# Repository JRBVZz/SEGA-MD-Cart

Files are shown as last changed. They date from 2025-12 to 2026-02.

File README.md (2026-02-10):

#### SEGA MD Cart - картридж для SEGA MegaDrive/Genesis

Простой картридж объемом до 4MB (32Mbit) без сохранений, который можно перезаписывать с помощью программатора [FlashKit MD](https://github.com/JRBVZz/Flashkit-MD).

10.02.2026. Добавил проект PCB с возможностью установки памяти MX29L3211 в корпусе SOP-44.

Для хранения данных используется flash память в корпусе TSOP-48 - S29GL032, MX29LV320, M29W320 и др. Для игр до 2MB можно использовать память меньшего объема.

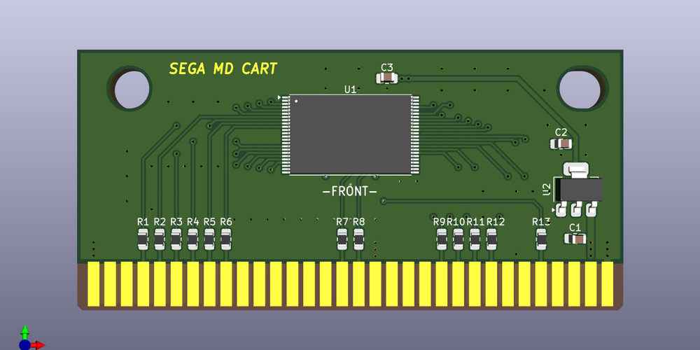
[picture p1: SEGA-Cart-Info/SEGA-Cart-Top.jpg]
3D Top
 

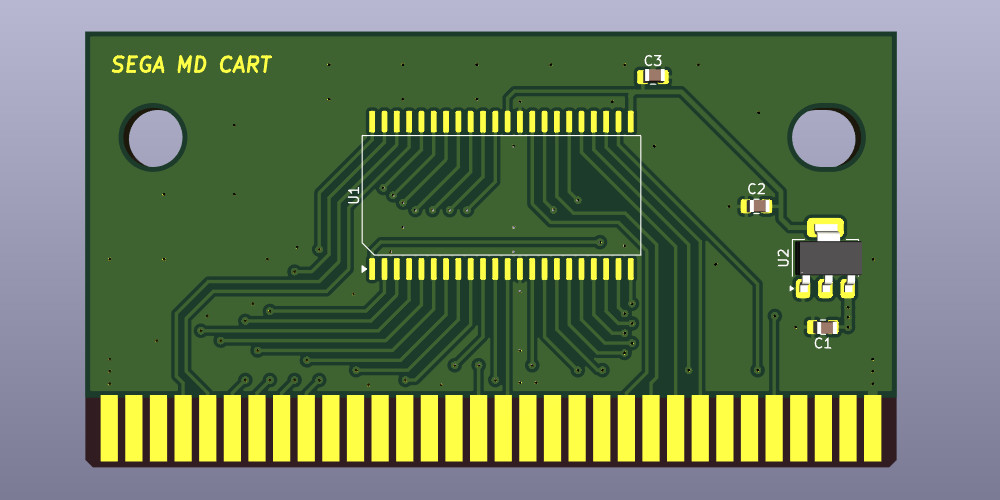
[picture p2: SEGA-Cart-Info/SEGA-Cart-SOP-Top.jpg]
3D Top-SOP


**Параметры для изготовления PCB**  
* 2 слоя
* Толщина PCB: 1.6 мм
* Рекомендуется ENIG покрытие контактов краевого разъема

**Схемы**  
[Schematic PDF](SEGA-Cart-Info/SEGA-Cart-Schematic.pdf)  
[Schematic PDF SOP](SEGA-Cart-Info/SEGA-Cart-SOP-Schematic.pdf)

**Интерактивный BOM**  
[BoM](SEGA-Cart-Info/SEGA-Cart-iBOM.html) (для корректного просмотра нужно скачать raw файл)  
[BoM-SOP](SEGA-Cart-Info/SEGA-Cart-SOP-iBOM.html) (для корректного просмотра нужно скачать raw файл)

Проект создан в [**KiCad 9**](https://www.kicad.org/).

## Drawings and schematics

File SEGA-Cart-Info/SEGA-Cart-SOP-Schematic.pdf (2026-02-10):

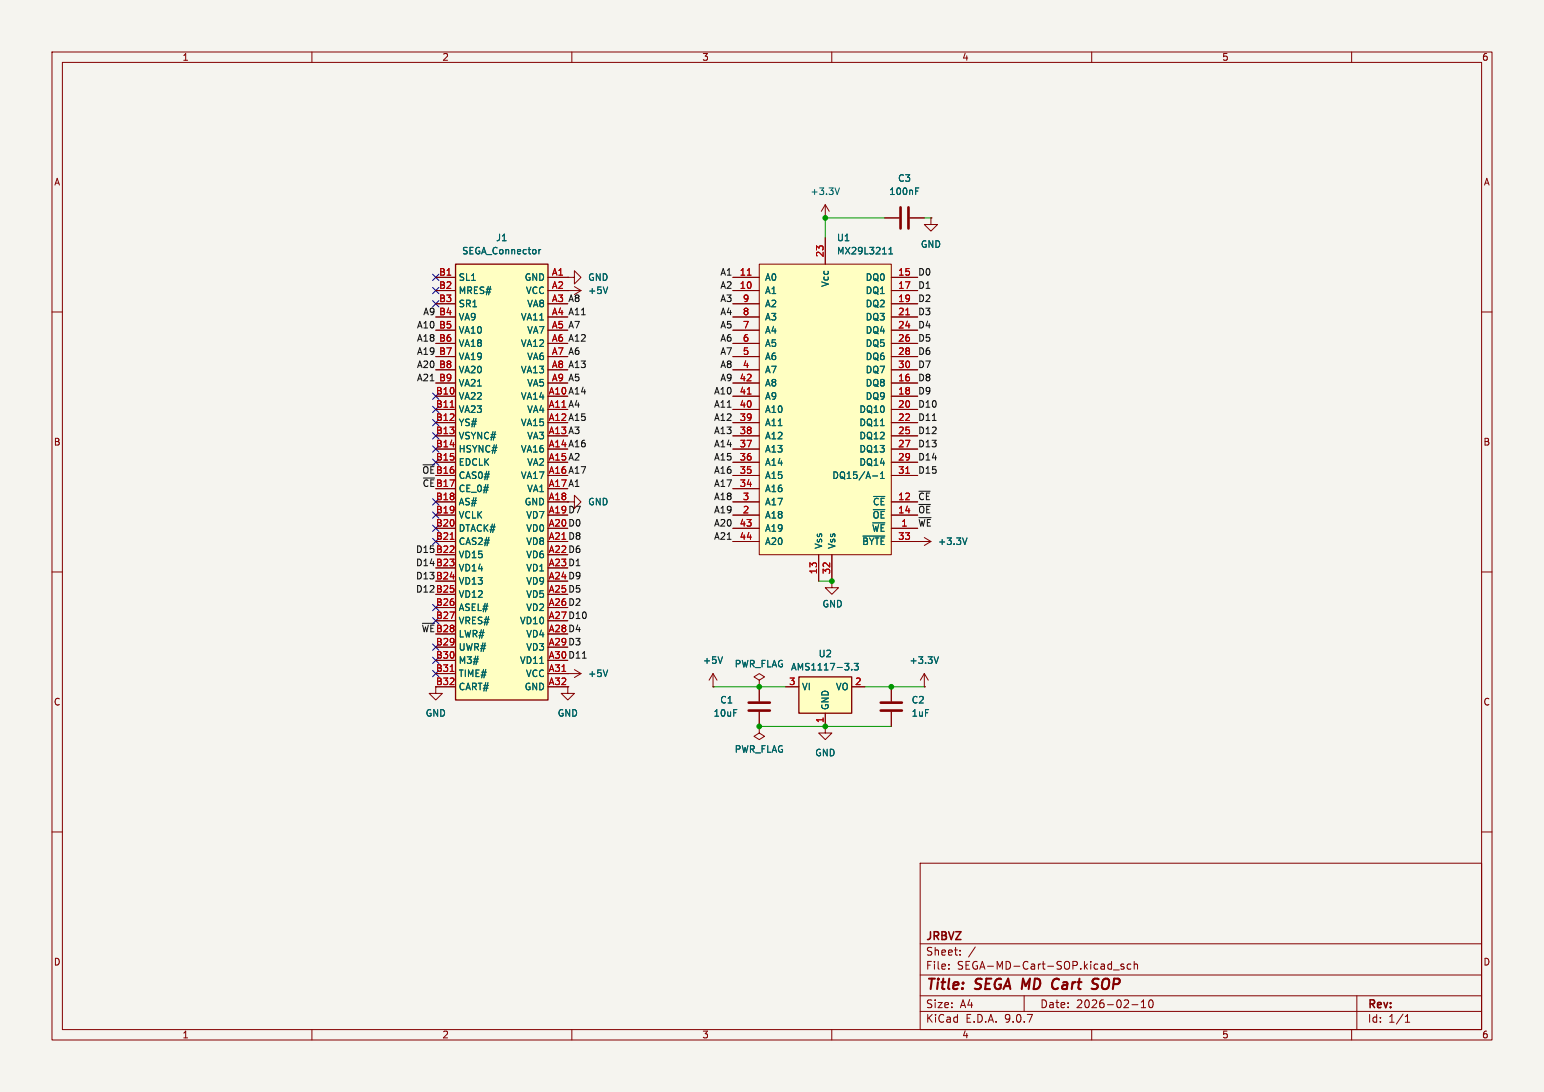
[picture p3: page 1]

File: SEGA-MD-Cart-SOP.kicad_sch Sheet: / JRBVZ GND GND

Id: 1/1 Title: SEGA MD Cart SOP

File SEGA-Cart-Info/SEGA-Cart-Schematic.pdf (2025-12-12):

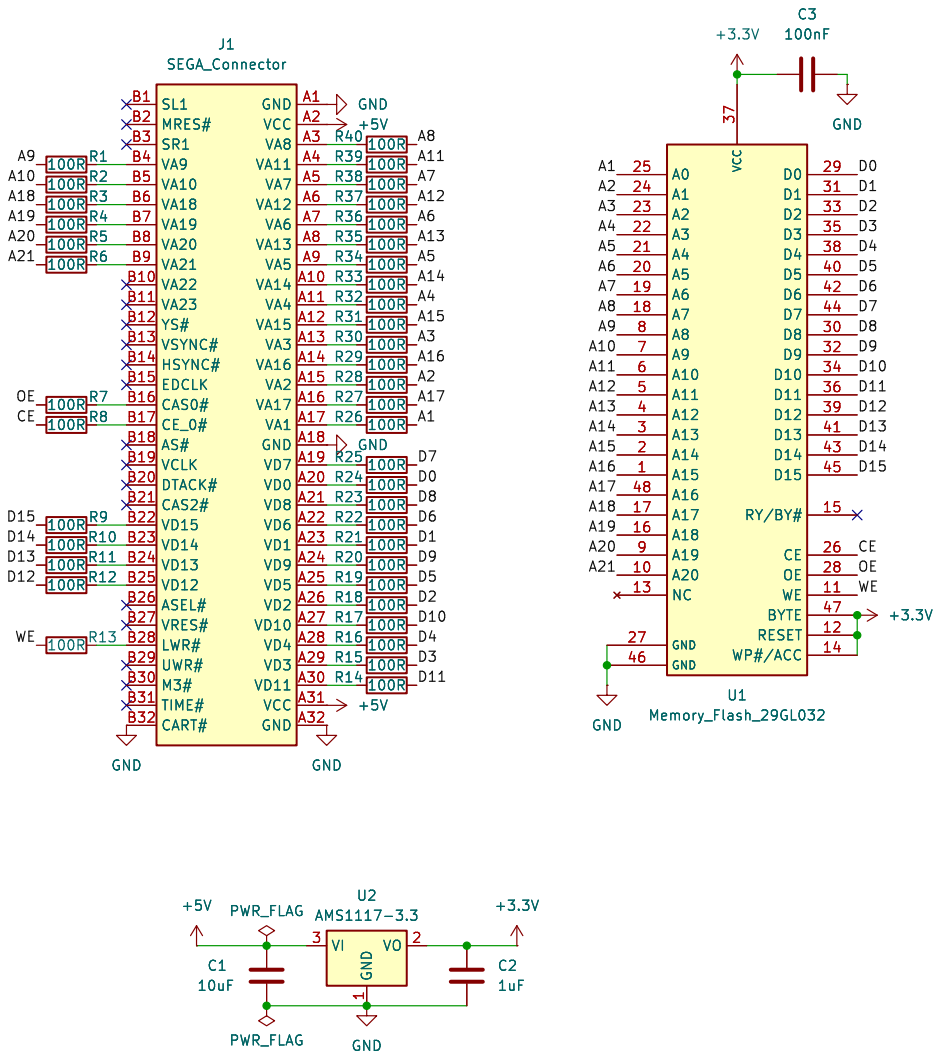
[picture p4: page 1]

Id: 1/1 Title: SEGA MD Cart File: SEGA-MD-Cart.kicad_sch Sheet: / JRBVZ

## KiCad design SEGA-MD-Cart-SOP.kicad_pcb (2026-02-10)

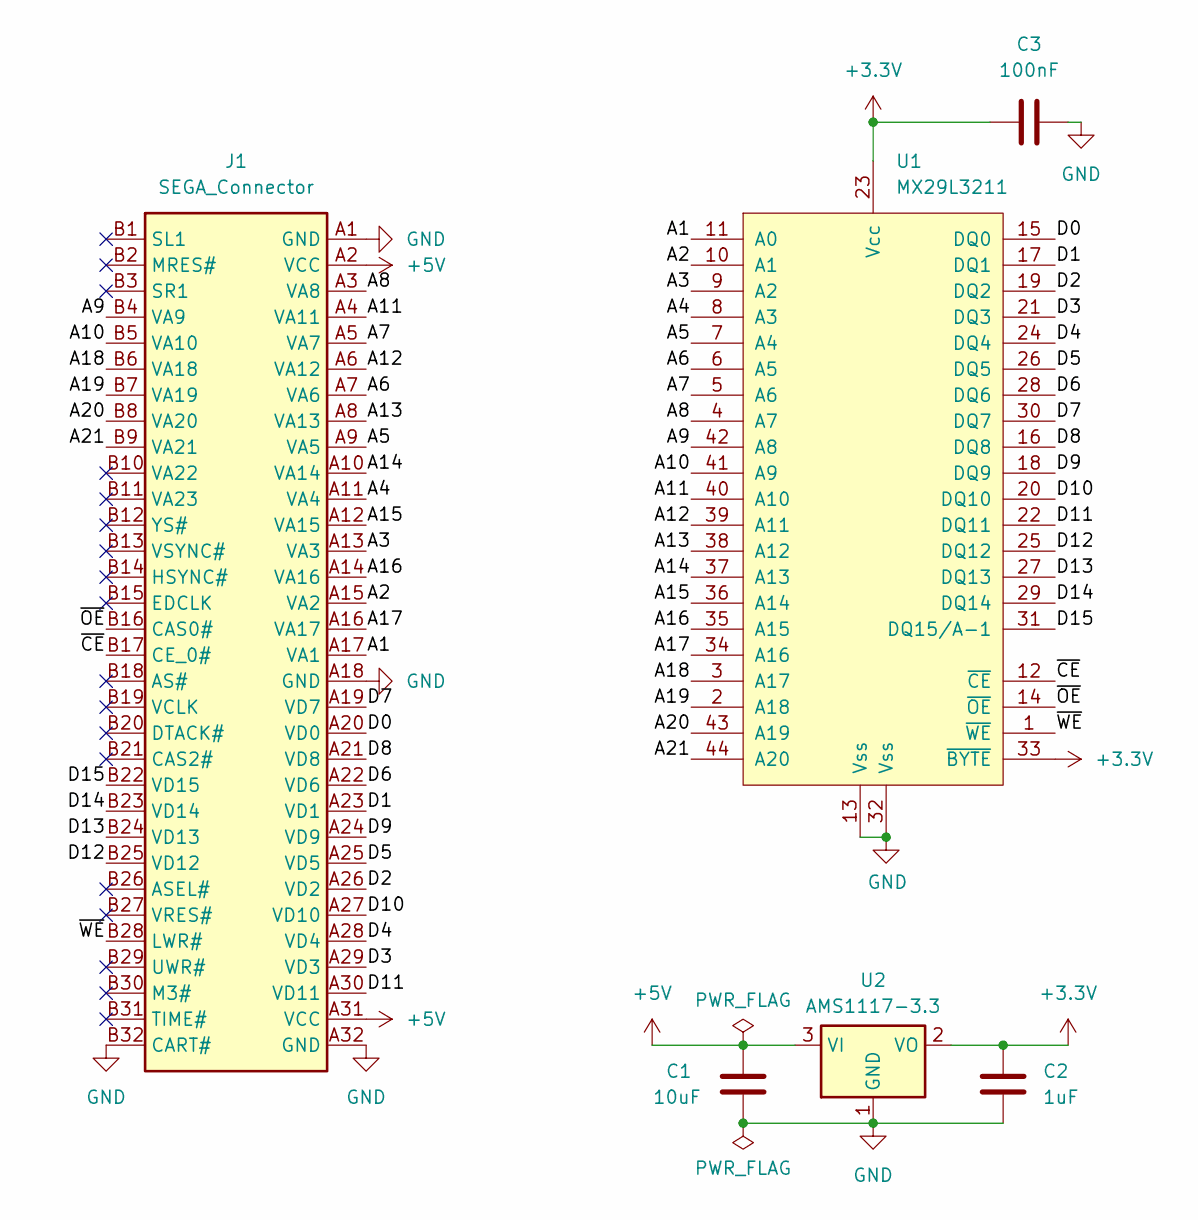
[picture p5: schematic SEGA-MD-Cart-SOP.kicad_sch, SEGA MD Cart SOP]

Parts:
C1: 10uF; C_0805_2012Metric_Pad1.18x1.45mm_HandSolder
C2: 1uF; C_0805_2012Metric_Pad1.18x1.45mm_HandSolder
C3: 100nF; C_0805_2012Metric_Pad1.18x1.45mm_HandSolder
J1: SEGA_Connector
U1: MX29L3211; SOP-44_P1.27mm_HandSolder
U2: AMS1117-3.3; SOT-223-3_TabPin2

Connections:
+3.3V: C2.1, C3.2, U1.23 (Vcc), U1.33 (~BYTE), U2.2 (VO)
+5V: C1.1, J1.A2 (VCC), J1.A31 (VCC), U2.3 (VI)
/A1: J1.A17 (VA1), U1.11 (A0)
/A2: J1.A15 (VA2), U1.10 (A1)
/A3: J1.A13 (VA3), U1.9 (A2)
/A4: J1.A11 (VA4), U1.8 (A3)
/A5: J1.A9 (VA5), U1.7 (A4)
/A6: J1.A7 (VA6), U1.6 (A5)
/A7: J1.A5 (VA7), U1.5 (A6)
/A8: J1.A3 (VA8), U1.4 (A7)
/A9: J1.B4 (VA9), U1.42 (A8)
/A10: J1.B5 (VA10), U1.41 (A9)
/A11: J1.A4 (VA11), U1.40 (A10)
/A12: J1.A6 (VA12), U1.39 (A11)
/A13: J1.A8 (VA13), U1.38 (A12)
/A14: J1.A10 (VA14), U1.37 (A13)
/A15: J1.A12 (VA15), U1.36 (A14)
/A16: J1.A14 (VA16), U1.35 (A15)
/A17: J1.A16 (VA17), U1.34 (A16)
/A18: J1.B6 (VA18), U1.3 (A17)
/A19: J1.B7 (VA19), U1.2 (A18)
/A20: J1.B8 (VA20), U1.43 (A19)
/A21: J1.B9 (VA21), U1.44 (A20)
/D0: J1.A20 (VD0), U1.15 (DQ0)
/D1: J1.A23 (VD1), U1.17 (DQ1)
/D2: J1.A26 (VD2), U1.19 (DQ2)
/D3: J1.A29 (VD3), U1.21 (DQ3)
/D4: J1.A28 (VD4), U1.24 (DQ4)
/D5: J1.A25 (VD5), U1.26 (DQ5)
/D6: J1.A22 (VD6), U1.28 (DQ6)
/D7: J1.A19 (VD7), U1.30 (DQ7)
/D8: J1.A21 (VD8), U1.16 (DQ8)
/D9: J1.A24 (VD9), U1.18 (DQ9)
/D10: J1.A27 (VD10), U1.20 (DQ10)
/D11: J1.A30 (VD11), U1.22 (DQ11)
/D12: J1.B25 (VD12), U1.25 (DQ12)
/D13: J1.B24 (VD13), U1.27 (DQ13)
/D14: J1.B23 (VD14), U1.29 (DQ14)
/D15: J1.B22 (VD15), U1.31 (DQ15/A-1)
/~CE: J1.B17 (CE_0#), U1.12 (~CE)
/~OE: J1.B16 (CAS0#), U1.14 (~OE)
/~WE: J1.B28 (LWR#), U1.1 (~WE)
GND: C1.2, C2.2, C3.1, J1.A1 (GND), J1.A18 (GND), J1.A32 (GND), J1.B32 (CART#), U1.13 (Vss), U1.32 (Vss), U2.1 (GND)

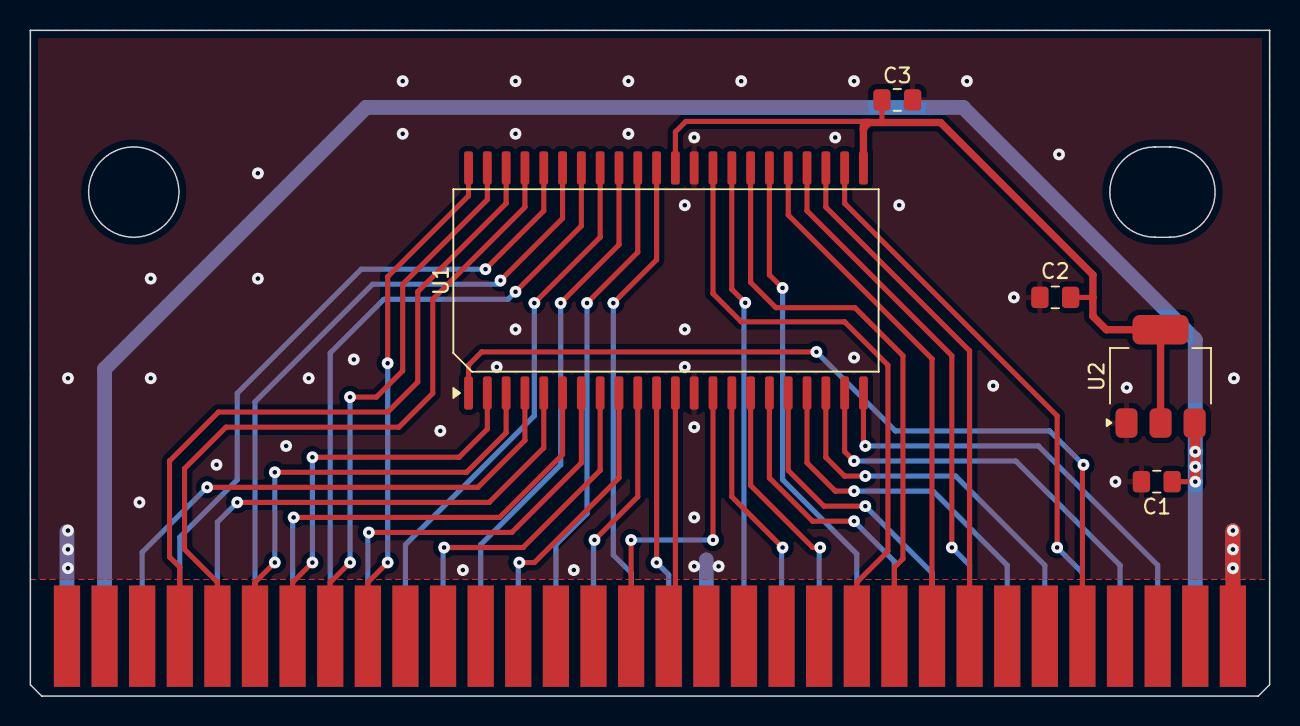
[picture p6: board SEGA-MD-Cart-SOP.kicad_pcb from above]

Board: 2 copper layers, 83.7 x 45.0 mm, 6 parts (0 on the bottom side), 43 nets.

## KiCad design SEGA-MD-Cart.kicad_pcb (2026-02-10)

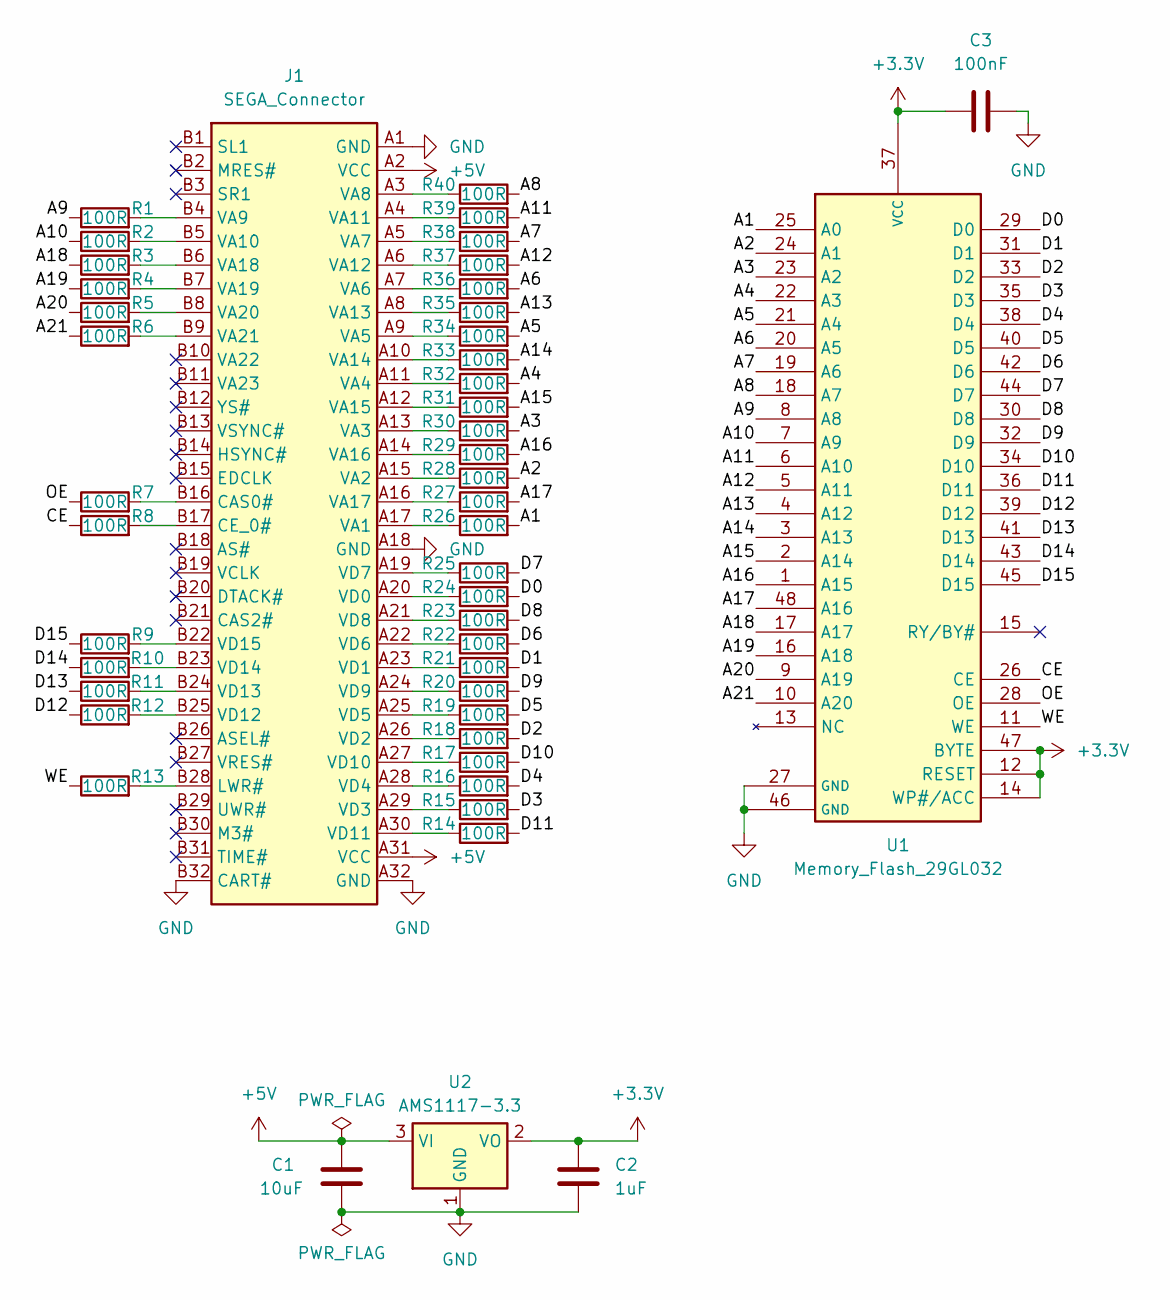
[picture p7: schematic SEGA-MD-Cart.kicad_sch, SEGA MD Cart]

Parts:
C1: 10uF; C_0805_2012Metric_Pad1.18x1.45mm_HandSolder
C2: 1uF; C_0805_2012Metric_Pad1.18x1.45mm_HandSolder
C3: 100nF; C_0805_2012Metric_Pad1.18x1.45mm_HandSolder
J1: SEGA_Connector
R1, R2, R3, R4, R5, R6, R7, R8, R9, R10, R11, R12, R13, R14, R15, R16, R17, R18, R19, R20, R21, R22, R23, R24, R25, R26, R27, R28, R29, R30, R31, R32, R33, R34, R35, R36, R37, R38, R39, R40: 100R; R_0805_2012Metric_Pad1.20x1.40mm_HandSolder
U1: Memory_Flash_29GL032; TSOP-I-48_18.4x12mm_P0.5mm
U2: AMS1117-3.3; SOT-223-3_TabPin2

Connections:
+3.3V: C2.1, C3.2, U1.12 (RESET), U1.14 (WP#/ACC), U1.37 (VCC), U1.47 (BYTE), U2.2 (VO)
+5V: C1.1, J1.A2 (VCC), J1.A31 (VCC), U2.3 (VI)
/A1: R26.2, U1.25 (A0)
/A2: R28.2, U1.24 (A1)
/A3: R30.2, U1.23 (A2)
/A4: R32.2, U1.22 (A3)
/A5: R34.2, U1.21 (A4)
/A6: R36.2, U1.20 (A5)
/A7: R38.2, U1.19 (A6)
/A8: R40.2, U1.18 (A7)
/A9: R1.1, U1.8 (A8)
/A10: R2.1, U1.7 (A9)
/A11: R39.2, U1.6 (A10)
/A12: R37.2, U1.5 (A11)
/A13: R35.2, U1.4 (A12)
/A14: R33.2, U1.3 (A13)
/A15: R31.2, U1.2 (A14)
/A16: R29.2, U1.1 (A15)
/A17: R27.2, U1.48 (A16)
/A18: R3.1, U1.17 (A17)
/A19: R4.1, U1.16 (A18)
/A20: R5.1, U1.9 (A19)
/A21: R6.1, U1.10 (A20)
/CE: R8.1, U1.26 (CE)
/D0: R24.2, U1.29 (D0)
/D1: R21.2, U1.31 (D1)
/D2: R18.2, U1.33 (D2)
/D3: R15.2, U1.35 (D3)
/D4: R16.2, U1.38 (D4)
/D5: R19.2, U1.40 (D5)
/D6: R22.2, U1.42 (D6)
/D7: R25.2, U1.44 (D7)
/D8: R23.2, U1.30 (D8)
/D9: R20.2, U1.32 (D9)
/D10: R17.2, U1.34 (D10)
/D11: R14.2, U1.36 (D11)
/D12: R12.1, U1.39 (D12)
/D13: R11.1, U1.41 (D13)
/D14: R10.1, U1.43 (D14)
/D15: R9.1, U1.45 (D15)
/OE: R7.1, U1.28 (OE)
/WE: R13.1, U1.11 (WE)
GND: C1.2, C2.2, C3.1, J1.A1 (GND), J1.A18 (GND), J1.A32 (GND), J1.B32 (CART#), U1.27 (GND), U1.46 (GND), U2.1 (GND)
unnamed: J1.B16 (CAS0#), R7.2
unnamed: J1.B17 (CE_0#), R8.2
unnamed: J1.B28 (LWR#), R13.2
unnamed: J1.A17 (VA1), R26.1
unnamed: J1.A15 (VA2), R28.1
unnamed: J1.A13 (VA3), R30.1
unnamed: J1.A11 (VA4), R32.1
unnamed: J1.A9 (VA5), R34.1
unnamed: J1.A7 (VA6), R36.1
unnamed: J1.A5 (VA7), R38.1
unnamed: J1.A3 (VA8), R40.1
unnamed: J1.B4 (VA9), R1.2
unnamed: J1.B5 (VA10), R2.2
unnamed: J1.A4 (VA11), R39.1
unnamed: J1.A6 (VA12), R37.1
unnamed: J1.A8 (VA13), R35.1
unnamed: J1.A10 (VA14), R33.1
unnamed: J1.A12 (VA15), R31.1
unnamed: J1.A14 (VA16), R29.1
unnamed: J1.A16 (VA17), R27.1
unnamed: J1.B6 (VA18), R3.2
unnamed: J1.B7 (VA19), R4.2
unnamed: J1.B8 (VA20), R5.2
unnamed: J1.B9 (VA21), R6.2
unnamed: J1.A20 (VD0), R24.1
unnamed: J1.A23 (VD1), R21.1
unnamed: J1.A26 (VD2), R18.1
unnamed: J1.A29 (VD3), R15.1
unnamed: J1.A28 (VD4), R16.1
unnamed: J1.A25 (VD5), R19.1
unnamed: J1.A22 (VD6), R22.1
unnamed: J1.A19 (VD7), R25.1
unnamed: J1.A21 (VD8), R23.1
unnamed: J1.A24 (VD9), R20.1
unnamed: J1.A27 (VD10), R17.1
unnamed: J1.A30 (VD11), R14.1
unnamed: J1.B25 (VD12), R12.2
unnamed: J1.B24 (VD13), R11.2
unnamed: J1.B23 (VD14), R10.2
unnamed: J1.B22 (VD15), R9.2

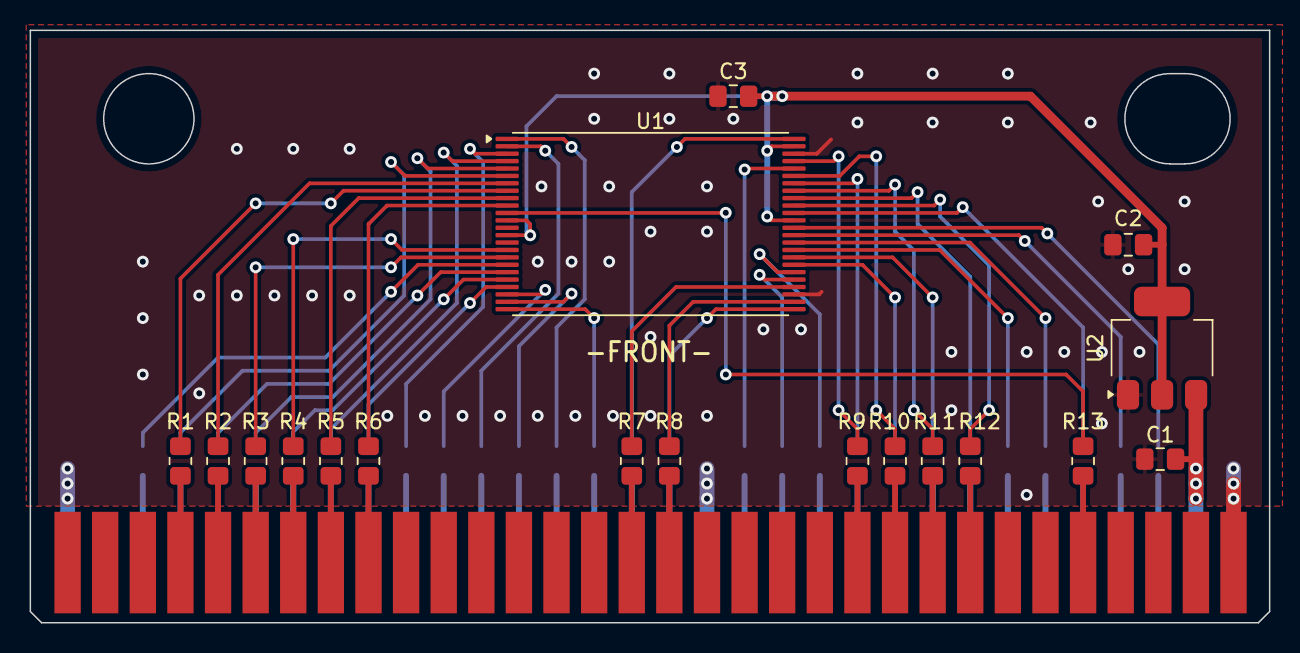
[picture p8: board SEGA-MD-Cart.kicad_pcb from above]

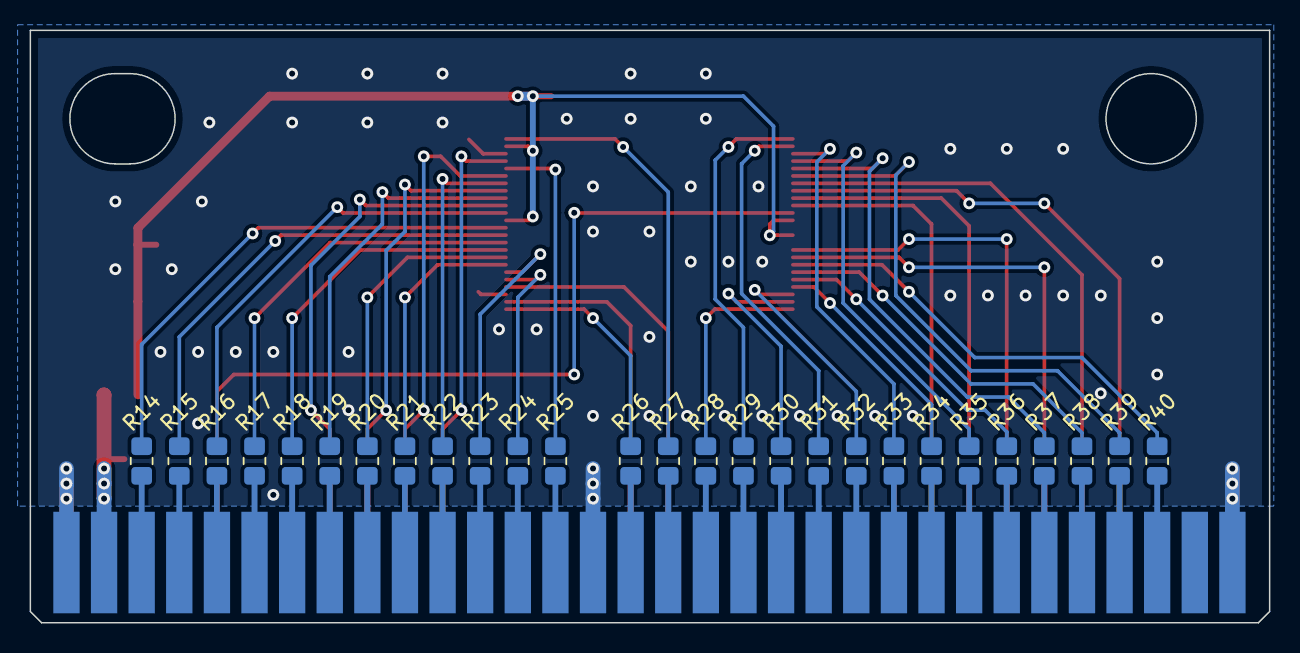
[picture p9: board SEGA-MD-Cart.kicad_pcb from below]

Board: 2 copper layers, 83.7 x 40.0 mm, 46 parts (27 on the bottom side), 83 nets.
